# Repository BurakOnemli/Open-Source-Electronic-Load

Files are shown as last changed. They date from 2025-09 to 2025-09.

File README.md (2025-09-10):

# Open-Source-Electronic-Load

Welcome to the **Open-Source Electronic Load** project!

WhatsApp Image 2025-09-10 at 20 56 23

This repository provides the design, source code, and documentation for a customizable, open-source electronic load. The project is developed in C and aims to offer a platform for electronics enthusiasts, students, and engineers who need a programmable load for testing power supplies, batteries, or other electronic circuits.

## Features

- Fully open-source hardware and firmware
- Designed for flexibility and expandability
- Suitable for testing DC power supplies and batteries
- Customizable load profiles (constant current, constant power, etc.)

## Repository Structure

- **Firmware**: Source code for the microcontroller that controls the electronic load
- **Hardware**: Schematics, PCB layouts, and hardware documentation
- **Documentation**: User guides and developer notes

## Getting Started

1. **Clone the repository:**  
   `git clone https://github.com/BurakOnemli/Open-Source-Electronic-Load.git`
2. **Review the hardware documents** to understand the design and required components.
3. **Build the hardware** according to the provided schematics and BOM.
4. **Flash the firmware** onto the chosen microcontroller.

## Dependencies

- STM32CubeIDE toolchain for programming the microcontroller
- KiCad for PCB design 
- Standard electronics lab tools for assembly

## Contributing

Contributions are welcome! You can contribute by:
- Submitting pull requests for code improvements or bug fixes
- Sharing hardware modifications
- Improving the documentation

Before contributing, please review any guidelines in the repository.

## License

This project is open-source. Please see the repository for license details.

## More Information

Check the [GitHub repository](https://github.com/BurakOnemli/Open-Source-Electronic-Load) for the latest updates, issues, and discussions.

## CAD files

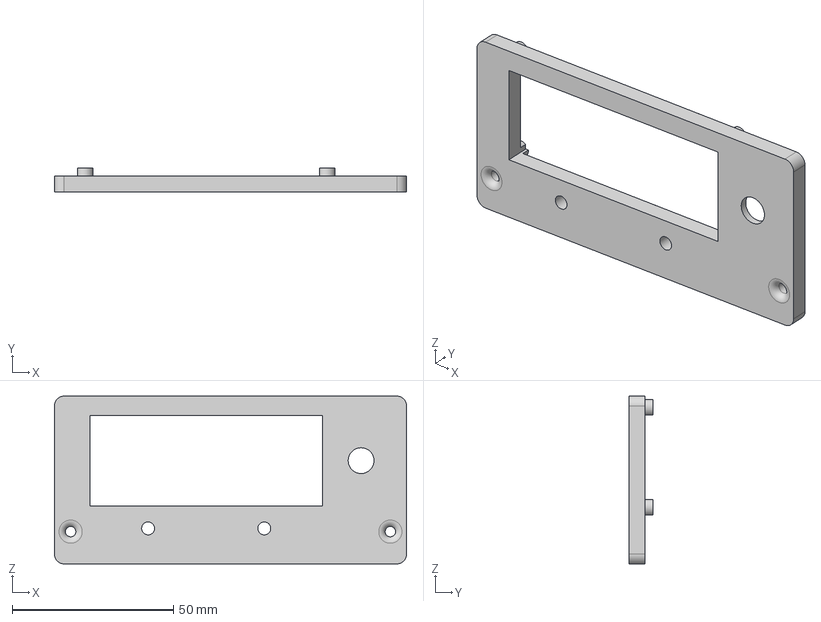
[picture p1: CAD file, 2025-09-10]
3D Files/Case_Lid.step
109.1 x 7.40 x 52.0 mm

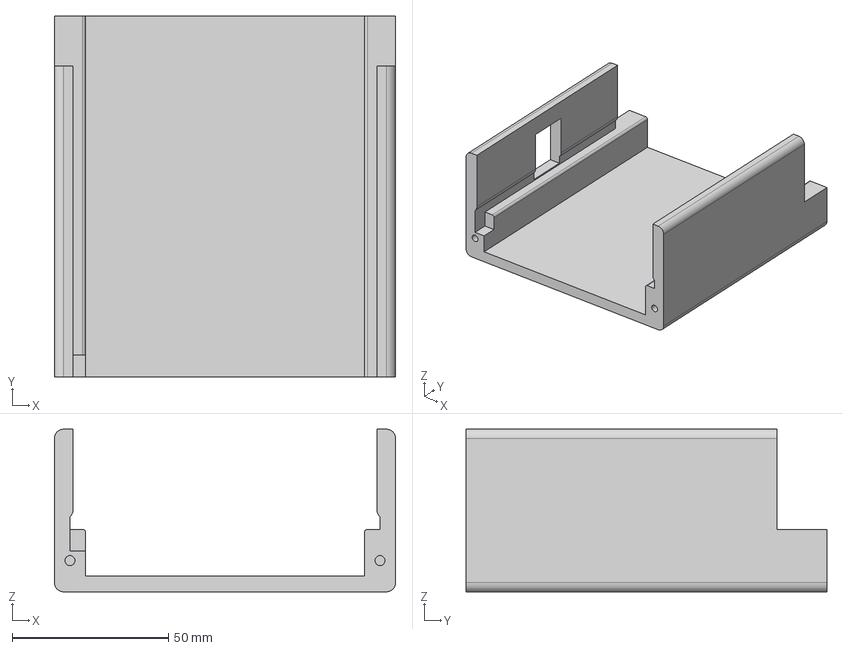
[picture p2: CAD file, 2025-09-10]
3D Files/Case_Body.step
109.1 x 115.3 x 52.0 mm

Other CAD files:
3D Files/Case_Body.f3d
3D Files/Case_Lid.f3d

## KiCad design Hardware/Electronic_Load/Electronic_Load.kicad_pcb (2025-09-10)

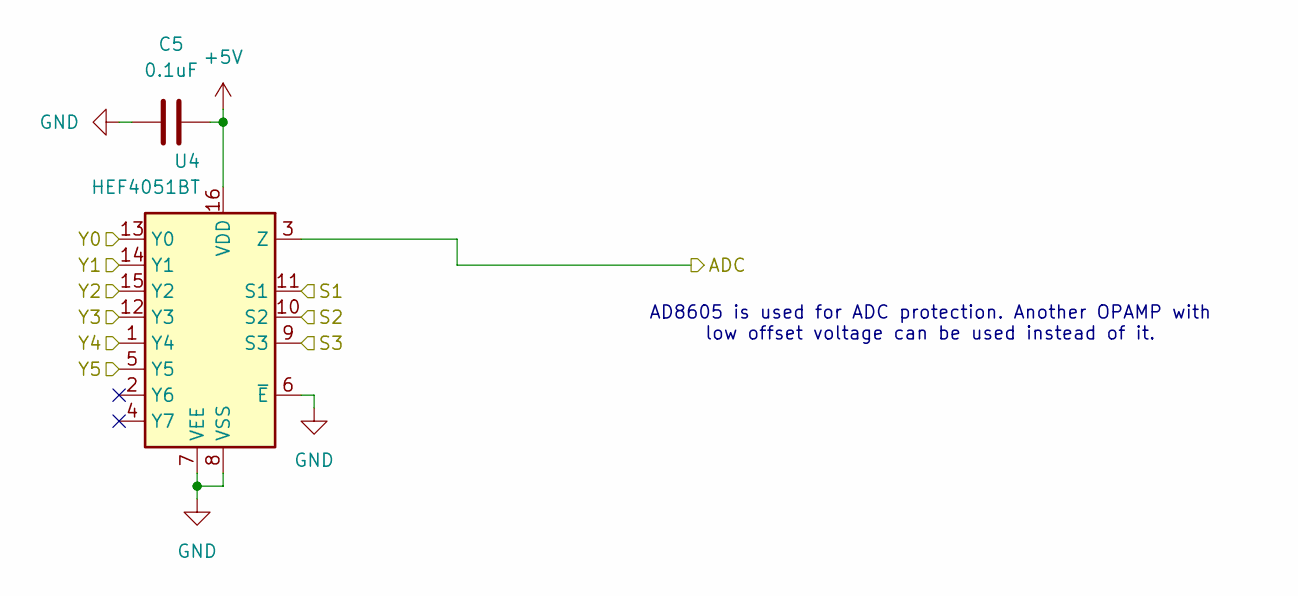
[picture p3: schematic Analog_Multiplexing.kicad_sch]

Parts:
C5: 0.1uF; C_0603_1608Metric
U4: HEF4051BT; SOIC-16_3.9x9.9mm_P1.27mm

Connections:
+5V: C5.2, U4.16 (VDD); also elsewhere on the board
/Analog_Multiplexing/ADC: U4.3 (Z); also elsewhere on the board
/Analog_Multiplexing/S1: U4.11 (S1); also elsewhere on the board
/Analog_Multiplexing/S2: U4.10 (S2); also elsewhere on the board
/Analog_Multiplexing/S3: U4.9 (S3); also elsewhere on the board
/Analog_Multiplexing/Y0: U4.13 (Y0); also elsewhere on the board
/Analog_Multiplexing/Y1: U4.14 (Y1); also elsewhere on the board
/Analog_Multiplexing/Y2: U4.15 (Y2); also elsewhere on the board
/Analog_Multiplexing/Y3: U4.12 (Y3); also elsewhere on the board
/Analog_Multiplexing/Y4: U4.1 (Y4); also elsewhere on the board
/Analog_Multiplexing/Y5: U4.5 (Y5); also elsewhere on the board
GND: C5.1, U4.6 (~E), U4.7 (VEE), U4.8 (VSS); also elsewhere on the board

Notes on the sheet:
AD8605 is used for ADC protection. Another OPAMP with low offset voltage can be used instead of it.

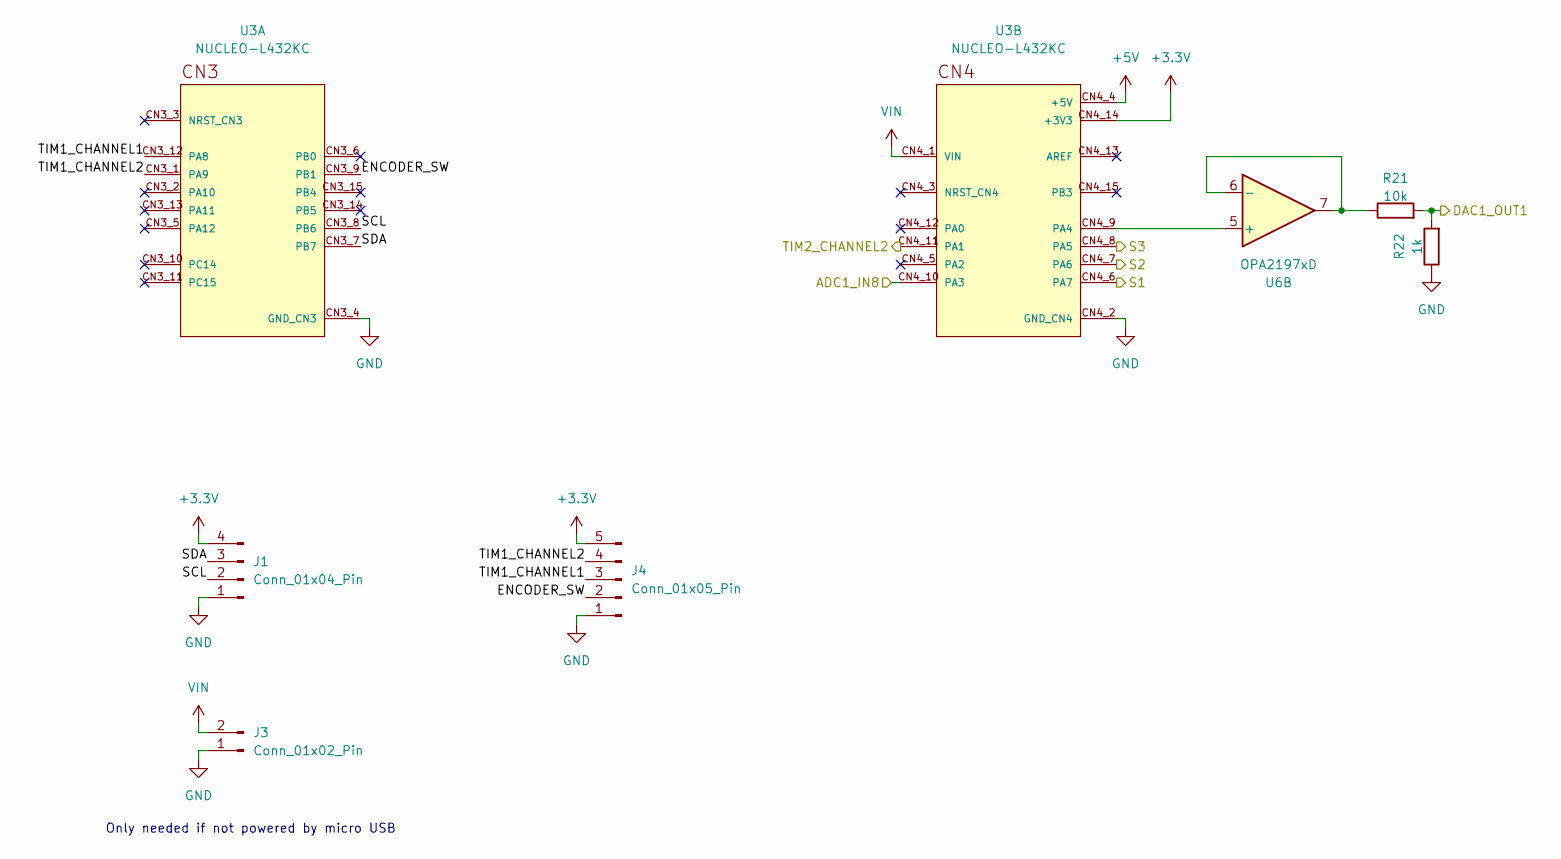
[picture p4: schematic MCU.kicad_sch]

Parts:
J1: Conn_01x04_Pin; PinHeader_1x04_P2.54mm_Vertical
J3: Conn_01x02_Pin; PinHeader_1x02_P2.54mm_Vertical
J4: Conn_01x05_Pin; PinHeader_1x05_P2.54mm_Vertical
R21: 10k; R_0603_1608Metric
R22: 1k; R_0603_1608Metric
U3: NUCLEO-L432KC; MODULE_NUCLEO-L432KC; PARTREV N/A
U6: OPA2197xD; SOIC-8_3.9x4.9mm_P1.27mm

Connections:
+3.3V: J1.4, J4.5, U3.CN4_14 (+3V3); also elsewhere on the board
+5V: U3.CN4_4 (+5V); also elsewhere on the board
/Analog_Multiplexing/ADC: U3.CN4_10 (PA3); also elsewhere on the board
/Analog_Multiplexing/S1: U3.CN4_6 (PA7); also elsewhere on the board
/Analog_Multiplexing/S2: U3.CN4_7 (PA6); also elsewhere on the board
/Analog_Multiplexing/S3: U3.CN4_8 (PA5); also elsewhere on the board
/Fan Controller/IN1: U3.CN4_11 (PA1); also elsewhere on the board
/Load Stage/DAC_BUFFERED: R21.2, R22.2; also elsewhere on the board
/MCU/ENCODER_SW: J4.2, U3.CN3_9 (PB1)
/MCU/SCL: J1.2, U3.CN3_8 (PB6)
/MCU/SDA: J1.3, U3.CN3_7 (PB7)
/MCU/TIM1_CHANNEL1: J4.3, U3.CN3_12 (PA8)
/MCU/TIM1_CHANNEL2: J4.4, U3.CN3_1 (PA9)
GND: J1.1, J3.1, J4.1, R22.1, U3.CN3_4 (GND_CN3), U3.CN4_2 (GND_CN4); also elsewhere on the board
unnamed: U3.CN4_9 (PA4), U6.5 (+)
unnamed: R21.1, U6.6 (-), U6.7
VIN: J3.2, U3.CN4_1 (VIN); also elsewhere on the board

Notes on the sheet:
Only needed if not powered by micro USB

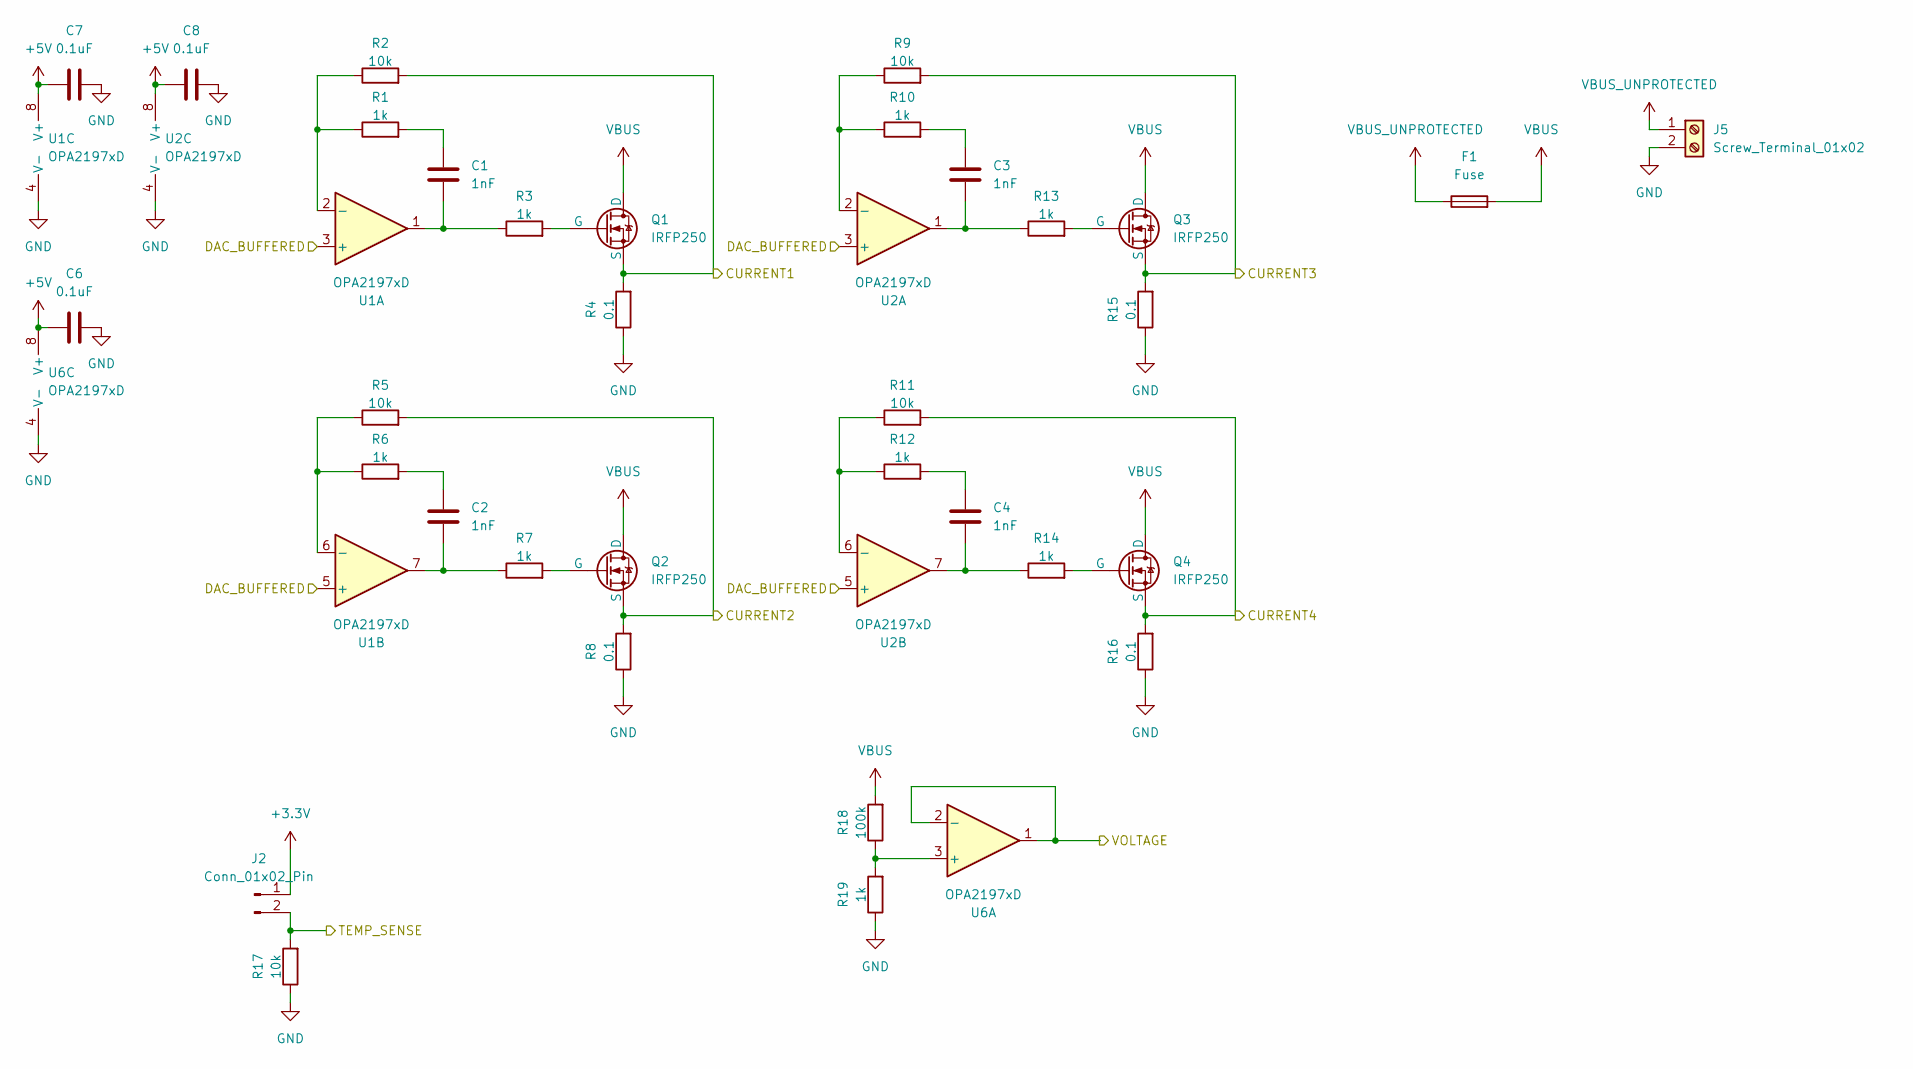
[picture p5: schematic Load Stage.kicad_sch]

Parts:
C1, C2, C3, C4: 1nF; C_0603_1608Metric
C6, C7, C8: 0.1uF; C_0603_1608Metric
F1: Fuse; Fuseholder_Cylinder-5x20mm_Schurter_0031_8201_Horizontal_Op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
J2: Conn_01x02_Pin; PinHeader_1x02_P2.54mm_Vertical
J5: Screw_Terminal_01x02; TerminalBlock_Wuerth_691311400102_P7.62mm
Q1, Q2, Q3, Q4: IRFP250; TO-247-3_Vertical
R1, R3, R6, R7, R10, R12, R13, R14, R19: 1k; R_0603_1608Metric
R2, R5, R9, R11, R17: 10k; R_0603_1608Metric
R4, R8, R15, R16: 0.1; R_2512_6332Metric_Pad1.40x3.35mm_HandSolder
R18: 100k; R_0603_1608Metric
U1, U2, U6: OPA2197xD; SOIC-8_3.9x4.9mm_P1.27mm

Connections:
+3.3V: J2.1; also elsewhere on the board
+5V: C6.1, C7.1, C8.1, U1.8 (V+), U2.8 (V+), U6.8 (V+); also elsewhere on the board
/Analog_Multiplexing/Y0: Q2.3 (S), R5.2, R8.2; also elsewhere on the board
/Analog_Multiplexing/Y1: Q3.3 (S), R9.2, R15.2; also elsewhere on the board
/Analog_Multiplexing/Y2: Q4.3 (S), R11.2, R16.2; also elsewhere on the board
/Analog_Multiplexing/Y3: Q1.3 (S), R2.2, R4.2; also elsewhere on the board
/Analog_Multiplexing/Y4: J2.2, R17.2; also elsewhere on the board
/Analog_Multiplexing/Y5: U6.1, U6.2 (-); also elsewhere on the board
/Load Stage/DAC_BUFFERED: U1.3 (+), U1.5 (+), U2.3 (+), U2.5 (+); also elsewhere on the board
GND: C6.2, C7.2, C8.2, J5.2, R4.1, R8.1, R15.1, R16.1, R17.1, R19.1, U1.4 (V-), U2.4 (V-), U6.4 (V-); also elsewhere on the board
unnamed: C1.1, R1.2
unnamed: C1.2, R3.1, U1.1
unnamed: C2.1, R6.2
unnamed: C2.2, R7.1, U1.7
unnamed: C3.1, R10.2
unnamed: C3.2, R13.1, U2.1
unnamed: C4.1, R12.2
unnamed: C4.2, R14.1, U2.7
unnamed: Q1.1 (G), R3.2
unnamed: Q2.1 (G), R7.2
unnamed: Q3.1 (G), R13.2
unnamed: Q4.1 (G), R14.2
unnamed: R1.1, R2.1, U1.2 (-)
unnamed: R5.1, R6.1, U1.6 (-)
unnamed: R9.1, R10.1, U2.2 (-)
unnamed: R11.1, R12.1, U2.6 (-)
unnamed: R18.1, R19.2, U6.3 (+)
VBUS: F1.2, Q1.2 (D), Q2.2 (D), Q3.2 (D), Q4.2 (D), R18.2
VBUS_UNPROTECTED: F1.1, J5.1

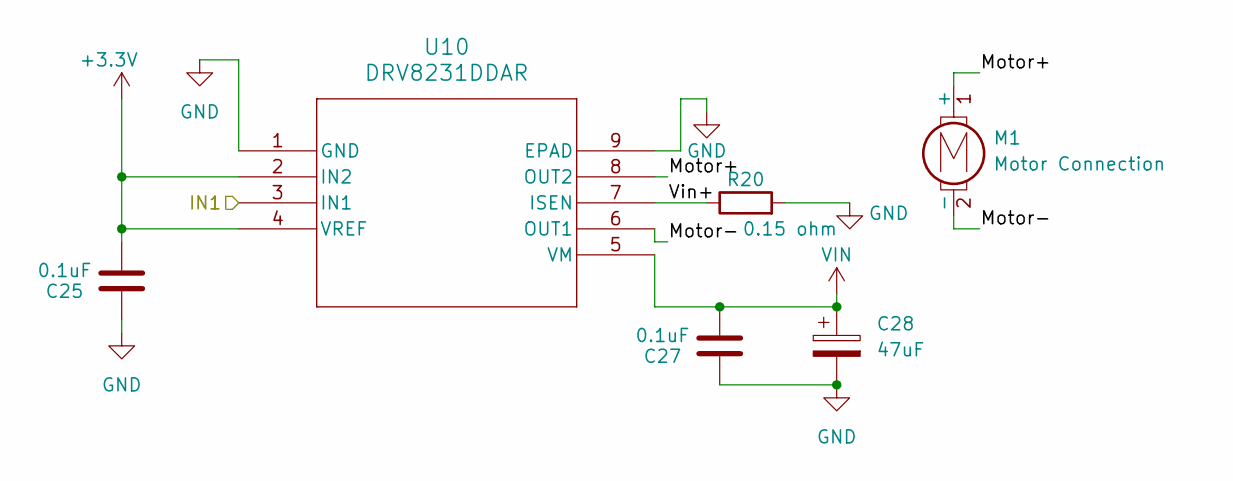
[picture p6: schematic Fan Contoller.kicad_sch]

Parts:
C25, C27: 0.1uF; C_0603_1608Metric
C28: 47uF; CP_EIA-6032-15_Kemet-U
M1: Motor Connection; PinHeader_1x02_P2.54mm_Vertical
R20: 0.15 ohm; R_2010_5025Metric
U10: DRV8231DDAR

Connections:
+3.3V: C25.2, U10.2 (IN2), U10.4 (VREF); also elsewhere on the board
/Fan Controller/IN1: U10.3 (IN1); also elsewhere on the board
/Fan Controller/Motor+: M1.1 (+), U10.8 (OUT2)
/Fan Controller/Motor-: M1.2 (-), U10.6 (OUT1)
/Fan Controller/Vin+: R20.1, U10.7 (ISEN)
GND: C25.1, C27.1, C28.2, R20.2, U10.1 (GND), U10.9 (EPAD); also elsewhere on the board
VIN: C27.2, C28.1, U10.5 (VM); also elsewhere on the board

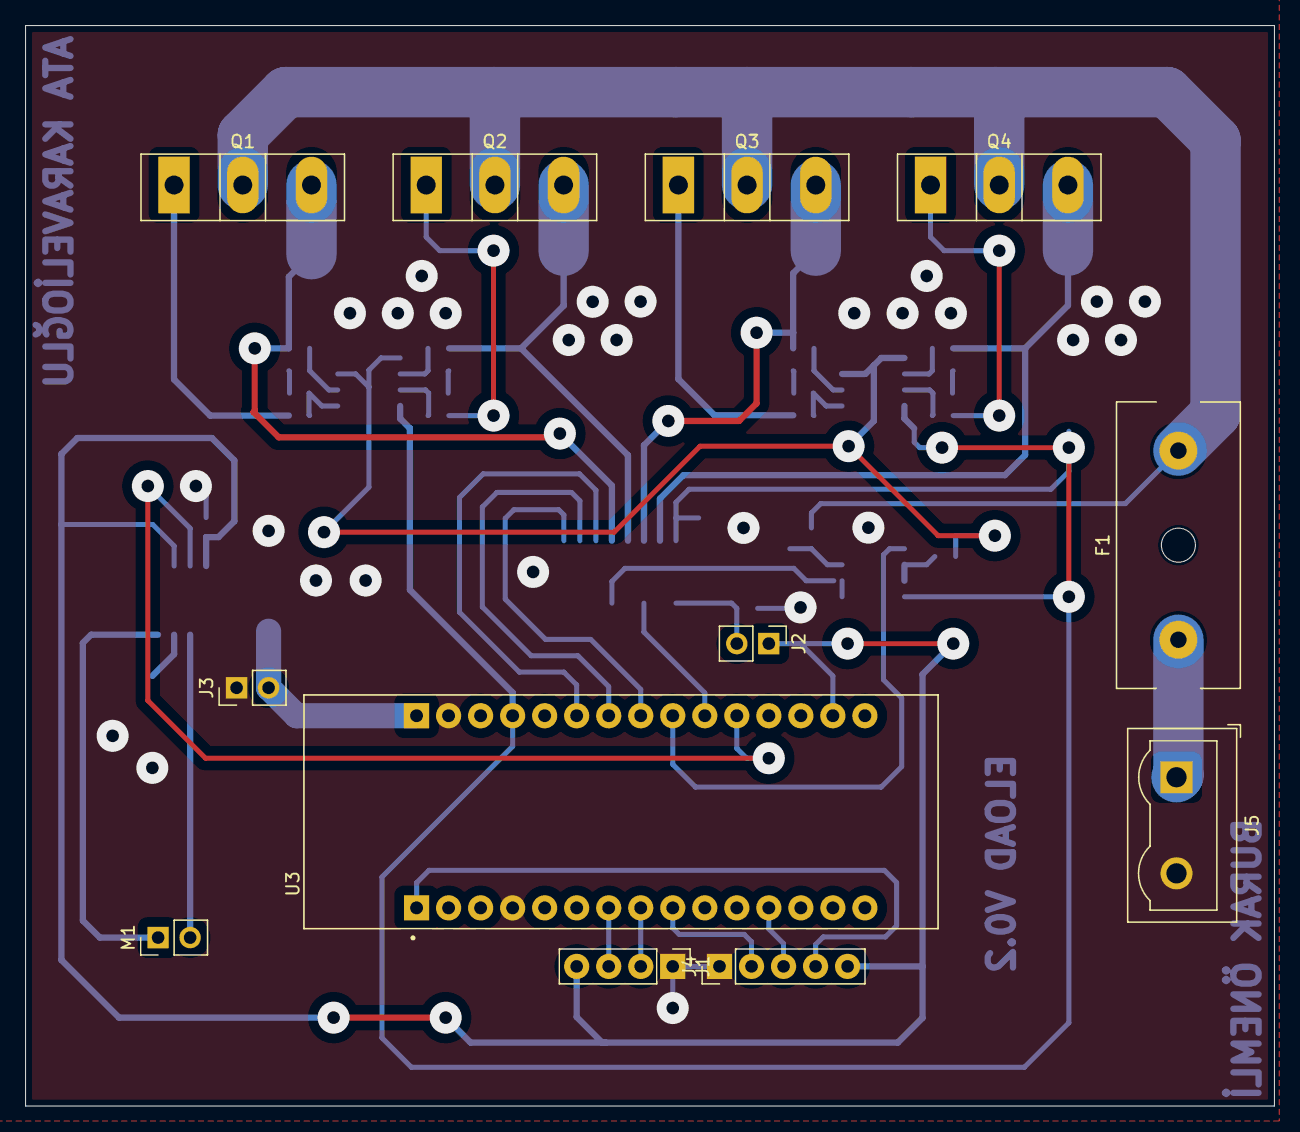
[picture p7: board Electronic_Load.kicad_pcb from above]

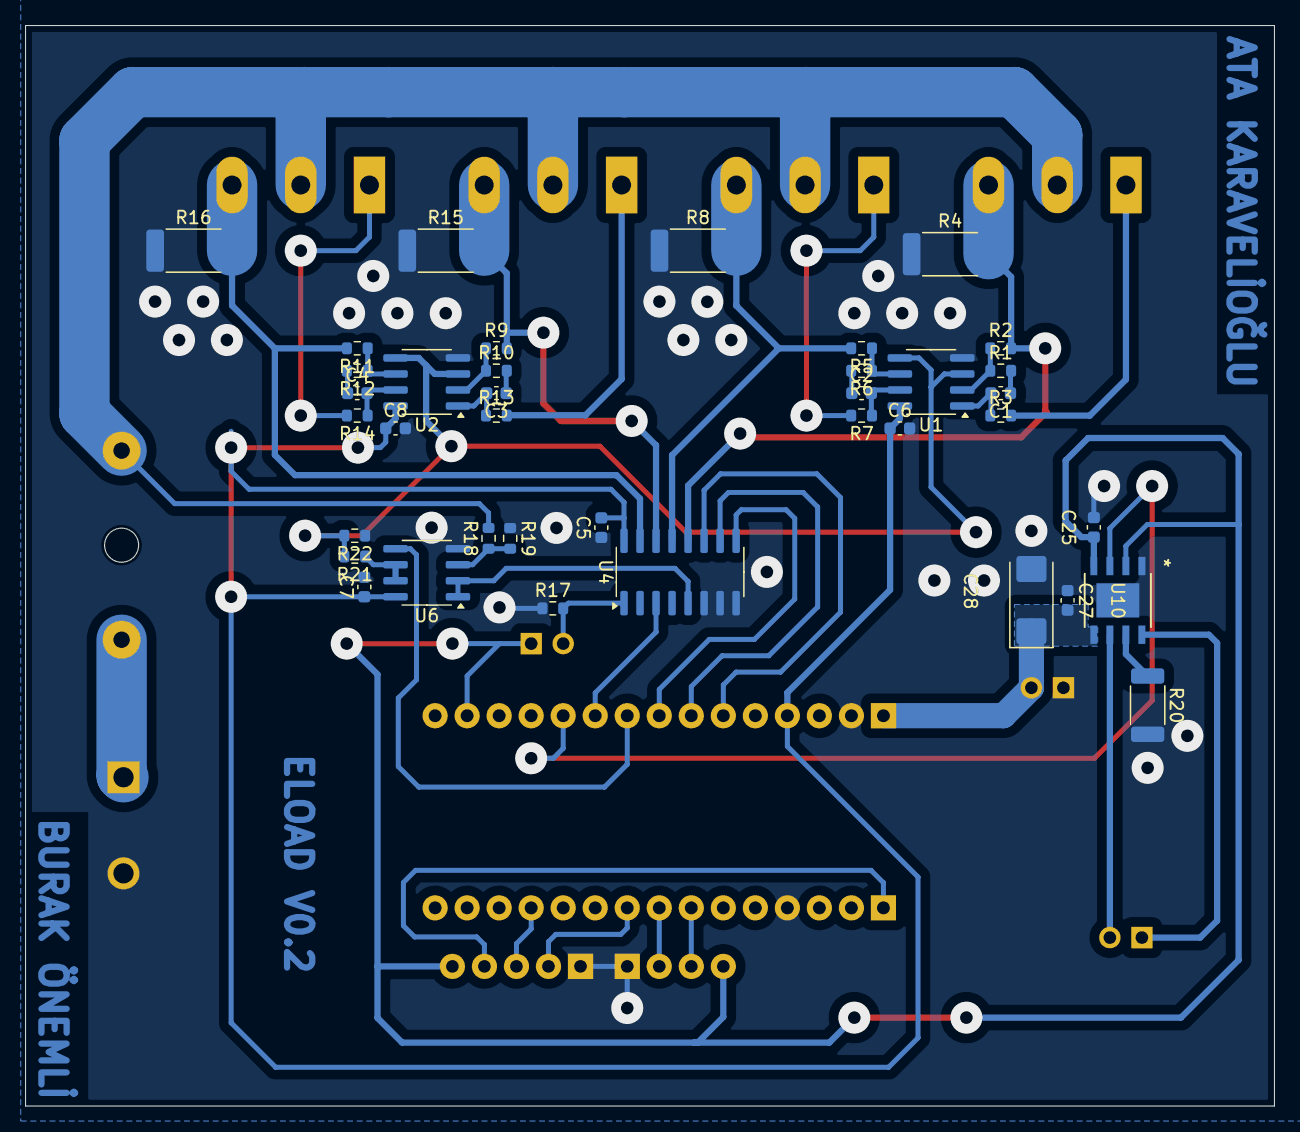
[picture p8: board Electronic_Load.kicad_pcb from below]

Board: 2 copper layers, 99.1 x 85.7 mm, 50 parts (38 on the bottom side), 45 nets.

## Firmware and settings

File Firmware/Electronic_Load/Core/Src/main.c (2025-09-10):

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
/* Includes ------------------------------------------------------------------*/
#include "main.h"

/* USER CODE BEGIN Includes */
#include "i2c_lcd.h"
#include "stdio.h"
#include "string.h"

/* USER CODE END Includes */

/* USER CODE BEGIN PD */
#define LCD_COLS 16
#define ENC_DEBOUNCE_MS   50   // 2–5 ms is typical for a mechanical encoder
#define PA_SEL_MASK (GPIO_PIN_5 | GPIO_PIN_6 | GPIO_PIN_7)
#define VREF 3.3
#define ADC_RES 4096.0

#define SEL_SHIFT 5
#define SEL_MASK  (0x7u << SEL_SHIFT)

#define UI_REFRESH_MS 500

/* USER CODE END PD */

ADC_HandleTypeDef hadc1;
DMA_HandleTypeDef hdma_adc1;

DAC_HandleTypeDef hdac1;

I2C_HandleTypeDef hi2c1;

TIM_HandleTypeDef htim1;
TIM_HandleTypeDef htim6;

UART_HandleTypeDef huart2;

/* USER CODE BEGIN PV */
volatile uint16_t ADC_Array[10];  //Data that is stored by the ADC
volatile uint16_t ADC_Filtered;
uint16_t DAC_Array[1]; 	//Data that is transferred to the DAC size will be kept at 1 until a test program is written
volatile uint32_t selectBits = 0;
volatile uint32_t changeBits = 0;
volatile uint8_t buttonPressed = 0;
uint8_t lastButtonState = 0;

volatile int16_t position = 0;
uint8_t direction = 0;
int16_t prePosition;
float currentSet = 0.0f;
// --- globals (or make them static in the .c file) ---
volatile uint8_t knobTurned = 0;

// last accepted capture time (ms). If you have multiple encoders/timers, keep one per encoder.
static uint32_t s_lastEncTick = 0;

uint32_t lastUiTick = 0;                  // last time we refreshed LCD/UI


float voltage = 3.14;

float current1 = 0;
float current2 = 0;
float current3 = 0;
float current4 = 0;
float previousCurrent = 0.0f;

char buffer[10];

/* USER CODE END PV */

void SystemClock_Config(void);
static void MX_GPIO_Init(void);
static void MX_DMA_Init(void);
static void MX_USART2_UART_Init(void);
static void MX_I2C1_Init(void);
static void MX_DAC1_Init(void);
static void MX_TIM1_Init(void);
static void MX_ADC1_Init(void);
static void MX_TIM6_Init(void);
/* USER CODE BEGIN PFP */
void PA_WriteSel3(uint32_t val3);
/* USER CODE END PFP */

/* USER CODE BEGIN 0 */

I2C_LCD_HandleTypeDef lcd1;
uint8_t addr = 0x3F;


/* USER CODE END 0 */

/**
  * @brief  The application entry point.
  * @retval int
  */
int main(void)
{

  /* MCU Configuration--------------------------------------------------------*/

  /* Reset of all peripherals, Initializes the Flash interface and the Systick. */
  HAL_Init();

  /* Configure the system clock */
  SystemClock_Config();

  /* Initialize all configured peripherals */
  MX_GPIO_Init();
  MX_DMA_Init();
  MX_USART2_UART_Init();
  MX_I2C1_Init();
  MX_DAC1_Init();
  MX_TIM1_Init();
  MX_ADC1_Init();
  MX_TIM6_Init();
  /* USER CODE BEGIN 2 */
  HAL_ADCEx_Calibration_Start(&hadc1, ADC_SINGLE_ENDED);
	lcd1.hi2c = &hi2c1;
	lcd1.address = addr;
	lcd_init(&lcd1);
	HAL_TIM_Base_Start_IT(&htim6);//DAC and ADC timer
	HAL_TIM_Encoder_Start_IT(&htim1, TIM_CHANNEL_ALL);
	HAL_ADC_Start_DMA(&hadc1, (uint32_t *)ADC_Array, 10);
	HAL_DAC_Start(&hdac1, DAC_CHANNEL_1);
	HAL_DAC_SetValue(&hdac1, DAC_CHANNEL_1, DAC_ALIGN_12B_R, 0);

  /* USER CODE END 2 */

  /* Infinite loop */
  /* USER CODE BEGIN WHILE */
	while (1)
	{

		uint32_t now = HAL_GetTick();
		uint8_t timeElapsed = (uint32_t)(now - lastUiTick) >= UI_REFRESH_MS;

		if ((knobTurned == 1) || (buttonPressed != lastButtonState) || timeElapsed)
		{
		    char buffer[LCD_COLS + 1];

		    // --- Row 1: Current ---
		    int n = snprintf(buffer, sizeof buffer, "I = ");
		    float power = 0.0f;

		    if (buttonPressed == 1) // SET MODE
		    {
		        uint32_t DAC_value = (uint32_t)(currentSet * 32.0f);
		        HAL_DAC_SetValue(&hdac1, DAC_CHANNEL_1, DAC_ALIGN_12B_R, DAC_value);

		        float current = 4.0f * current2;
		        power = current * voltage;
		        snprintf(buffer + n, sizeof buffer - n, "%.2f", current);
		    }
		    else
		    {
		        HAL_DAC_SetValue(&hdac1, DAC_CHANNEL_1, DAC_ALIGN_12B_R, 0);
		        if (((prePosition - position) > 0) && (knobTurned == 1)) {
		            direction = 0; currentSet = currentSet + 0.01f; prePosition = position;
		        } else if (((prePosition - position) <= 0) && (knobTurned == 1)) {
		            direction = 1; currentSet = currentSet - 0.01f; if (currentSet < 0.0f) currentSet = 0.0f; prePosition = position;
		        }
		        power = 0;
		        snprintf(buffer + n, sizeof buffer - n, "%.2f", currentSet);
		    }

		    size_t out_len = strlen(buffer);
		    if (out_len < LCD_COLS) memset(buffer + out_len, ' ', LCD_COLS - out_len);
		    buffer[LCD_COLS] = '\0';

		    // TOP-RIGHT 'S' only
		    buffer[LCD_COLS - 1] = (buttonPressed == 1) ? 'S' : ' ';

		    lcd_clear(&lcd1);
		    lcd_gotoxy(&lcd1, 0, 0);
		    lcd_puts(&lcd1, buffer, LCD_COLS);

		    // --- Row 2: Voltage + Wattage (no bottom-right S) ---
		    int m = snprintf(buffer, sizeof buffer, "V=%.2f W=%.2f", voltage, power);
		    out_len = (m > 0) ? (size_t)m : 0;
		    if (out_len < LCD_COLS) memset(buffer + out_len, ' ', LCD_COLS - out_len);
		    buffer[LCD_COLS] = '\0';                 // no marker at col 15

		    lcd_gotoxy(&lcd1, 0, 1);
		    lcd_puts(&lcd1, buffer, LCD_COLS);

		    knobTurned = 0;
		    lastButtonState = buttonPressed;
		    lastUiTick = now;
		}




    /* USER CODE END WHILE */

    /* USER CODE BEGIN 3 */
	}
  /* USER CODE END 3 */
}

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
/* USER CODE BEGIN 4 */
void HAL_TIM_PeriodElapsedCallback(TIM_HandleTypeDef *htim)
{



	uint16_t ADCFilteredSum = 0;
	ADC_Filtered = 0;
	for(int i = 0; i < 10;i++)
	{
		ADCFilteredSum = ADCFilteredSum + ADC_Array[i];
	}
	ADC_Filtered = ADCFilteredSum/10.0f;

	if (selectBits == 0) //2
	{
		current2 = VREF/ADC_RES * (float)ADC_Filtered * 10.0f;
	}
	else if (selectBits == 1) //3
	{

	}
	else if (selectBits == 2) //4
	{
		current4 = VREF/ADC_RES * (float)ADC_Filtered * 10.0f;
	}
	else if (selectBits == 3) //1
	{
		current1 = VREF/ADC_RES * (float)ADC_Filtered * 10.0f;
	}
	else if (selectBits == 4) //Temp
	{
		current3 = VREF/ADC_RES * (float)ADC_Filtered * 10.0f;
	}
	else if (selectBits == 5) //Voltage
	{
		voltage = (VREF/ADC_RES) * ((float)ADC_Filtered) * (101.0f); //101 is the (R1 + R2)/R1
	}

    // advance 0..5 (wrap)
    selectBits = selectBits + 1u;
//	selectBits = 0;
    if (selectBits > 5u) selectBits = 0u;

    // build masks for PA5..PA7  (uses your SEL_SHIFT=5, SEL_MASK=(0x7u<<5))
    uint16_t setMask = (uint16_t)(((selectBits & 0x7u) << SEL_SHIFT) & SEL_MASK);
    uint16_t rstMask = (uint16_t)(SEL_MASK & ~setMask);

    // update only PA5..PA7 via HAL (BSRR under the hood)
    if (rstMask) HAL_GPIO_WritePin(GPIOA, rstMask, GPIO_PIN_RESET);
    if (setMask) HAL_GPIO_WritePin(GPIOA, setMask, GPIO_PIN_SET);
}

void HAL_TIM_IC_CaptureCallback(TIM_HandleTypeDef* htim)
{
	// Debounce using SysTick
	uint32_t now = HAL_GetTick();
	if ((uint32_t)(now - s_lastEncTick) < ENC_DEBOUNCE_MS) {
		// too soon since the last accepted edge — ignore as bounce
		return;
	}
	s_lastEncTick = now;

	// Read encoder count and signal the main loop
	uint32_t counter = __HAL_TIM_GET_COUNTER(htim);
	int16_t count = (int16_t)counter;   // assuming ARR fits in int16_t / encoder configured that way
	position = count;
	knobTurned = 1;
}


void HAL_GPIO_EXTI_Callback(uint16_t GPIO_Pin)
{
	static uint32_t last = 0;
	if(GPIO_Pin == SW_Pin){
	        uint32_t now = HAL_GetTick();
	        if (now - last >= 400) {          // 50 ms example
	            last = now;
	            buttonPressed = !buttonPressed;   // or: mode ^= 1u;
	        }
	    }
}
void HAL_ADC_ConvCpltCallback(ADC_HandleTypeDef* hadc)
{


}

/* USER CODE END 4 */
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


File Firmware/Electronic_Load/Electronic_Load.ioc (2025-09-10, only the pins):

Mcu.UserName=STM32L432KCUx
PA0.GPIO_Label=MCO [High speed clock in]
PA0.Signal=RCC_CK_IN
PA2.GPIO_Label=VCP_TX
PA2.Signal=USART2_TX
PA3.Signal=ADCx_IN8
PA4.Signal=COMP_DAC11_group
PA5.GPIO_Label=S3
PA5.Signal=GPIO_Output
PA6.GPIO_Label=S2
PA6.Signal=GPIO_Output
PA7.GPIO_Label=S1
PA7.Signal=GPIO_Output
PA8.Signal=S_TIM1_CH1
PA9.Signal=S_TIM1_CH2
PB1.GPIO_Label=SW
PB1.Signal=GPXTI1
PB6.Signal=I2C1_SCL
PB7.Signal=I2C1_SDA

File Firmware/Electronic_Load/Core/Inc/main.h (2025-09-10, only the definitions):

#define MCO_Pin GPIO_PIN_0
#define MCO_GPIO_Port GPIOA
#define VCP_TX_Pin GPIO_PIN_2
#define VCP_TX_GPIO_Port GPIOA
#define S3_Pin GPIO_PIN_5
#define S3_GPIO_Port GPIOA
#define S2_Pin GPIO_PIN_6
#define S2_GPIO_Port GPIOA
#define S1_Pin GPIO_PIN_7
#define S1_GPIO_Port GPIOA
#define SW_Pin GPIO_PIN_1
#define SW_GPIO_Port GPIOB
#define SW_EXTI_IRQn EXTI1_IRQn
#define SWDIO_Pin GPIO_PIN_13
#define SWDIO_GPIO_Port GPIOA
#define SWCLK_Pin GPIO_PIN_14
#define SWCLK_GPIO_Port GPIOA
#define VCP_RX_Pin GPIO_PIN_15
#define VCP_RX_GPIO_Port GPIOA
#define LD3_Pin GPIO_PIN_3
#define LD3_GPIO_Port GPIOB

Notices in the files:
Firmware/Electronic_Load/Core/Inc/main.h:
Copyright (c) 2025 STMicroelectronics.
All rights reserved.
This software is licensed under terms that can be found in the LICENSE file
